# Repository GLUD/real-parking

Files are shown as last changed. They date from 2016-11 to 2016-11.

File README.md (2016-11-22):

# real-parking
Proyecto de Software y Hardware que pretente mejorar la movilidad de los parqueaderos a partir del análisis de datos.

Es un sistema escalable de parqueaderos. Busca ver toda la ciudad como un gran parqueadero y ayuda a gestionar de mejor manera el recurso espacial. Tiene un incentivo de gamificación con lo cuál se premia fidelidad a un parqueadero, entre otras cosas. Tiene un módulo de recomendaciones que dice cuál es el parqueadero mejor en relación precio/distancia del destino.

### INFORMACIÓN DE CONTACTO DESARROLLADORES ###

* Desarrollador: Jorge Ulises Useche Cuellar   
Ingeniero Electónico de la Udistrital FJC  
Movil: 3114813719  
Twitter: @juusechec   
LinkedIn: https://co.linkedin.com/in/juusechec  

* Desarrollador: Diego Javier Mena Amado  
Ingeniero Electrónico de la UDistrital FJC  
Movil: 3133067541  
Twitter: @DiegoJavierMena  
LinkedIn: https://www.linkedin.com/in/diego-javier-mena-amado-3357a873/en

* Desarrollador: Andrés Angarita  
Ingeniero de Sistemas de la UDistrital FJC  
Movil:   
Twitter: @   
LinkedIn:   

* Desarrollador: David Castelblanco  
Ingeniero de Sistemas de la UDistrital FJC  
Movil:   
Twitter: @   
LinkedIn:  

### Material de Presentación ###

https://www.youtube.com/watch?v=H8S8lVXx5Ek

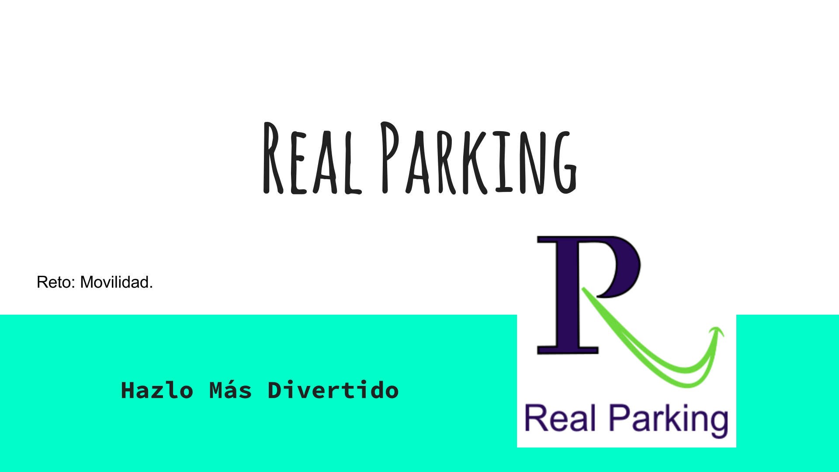
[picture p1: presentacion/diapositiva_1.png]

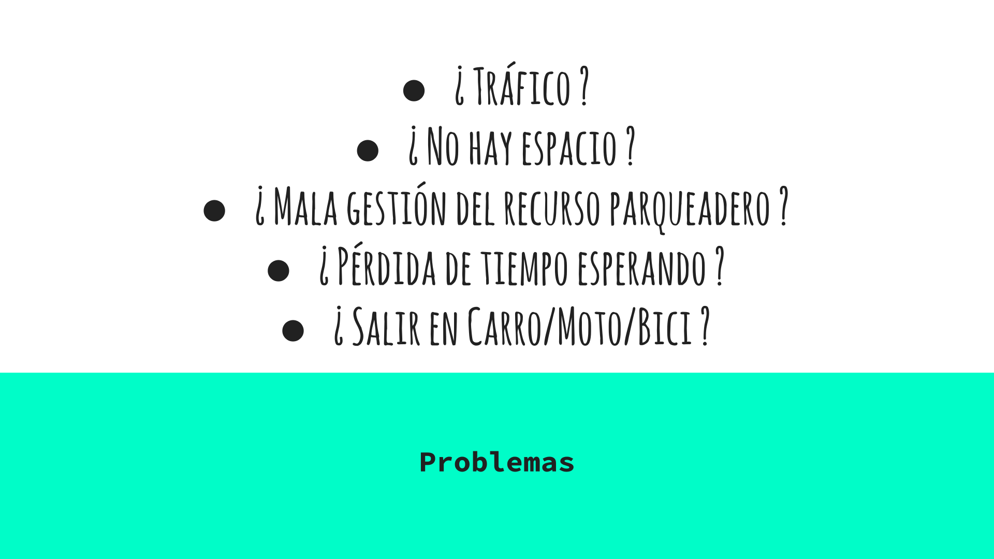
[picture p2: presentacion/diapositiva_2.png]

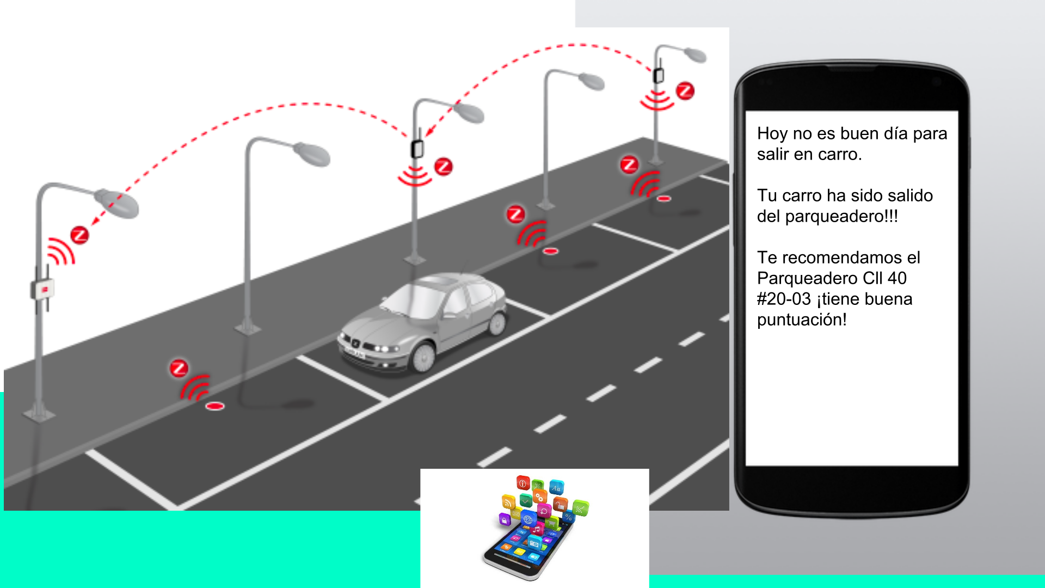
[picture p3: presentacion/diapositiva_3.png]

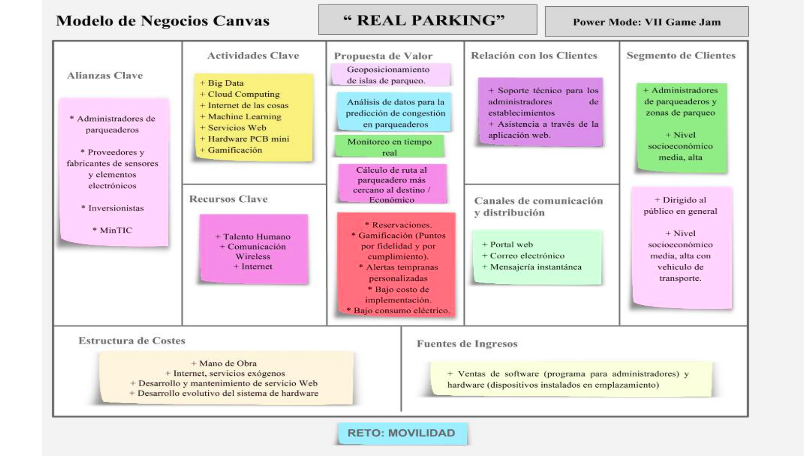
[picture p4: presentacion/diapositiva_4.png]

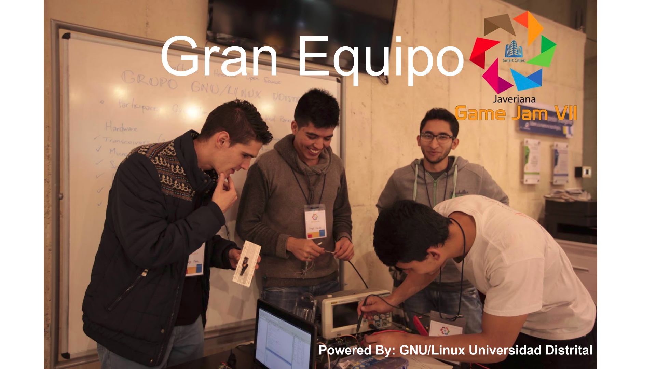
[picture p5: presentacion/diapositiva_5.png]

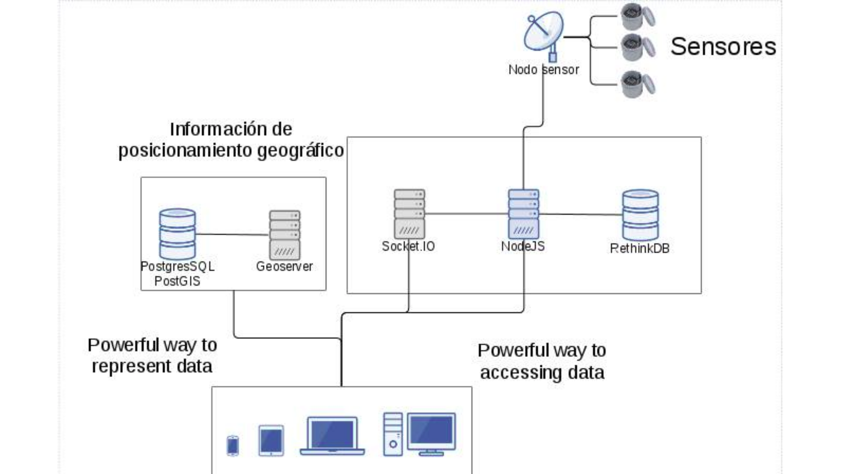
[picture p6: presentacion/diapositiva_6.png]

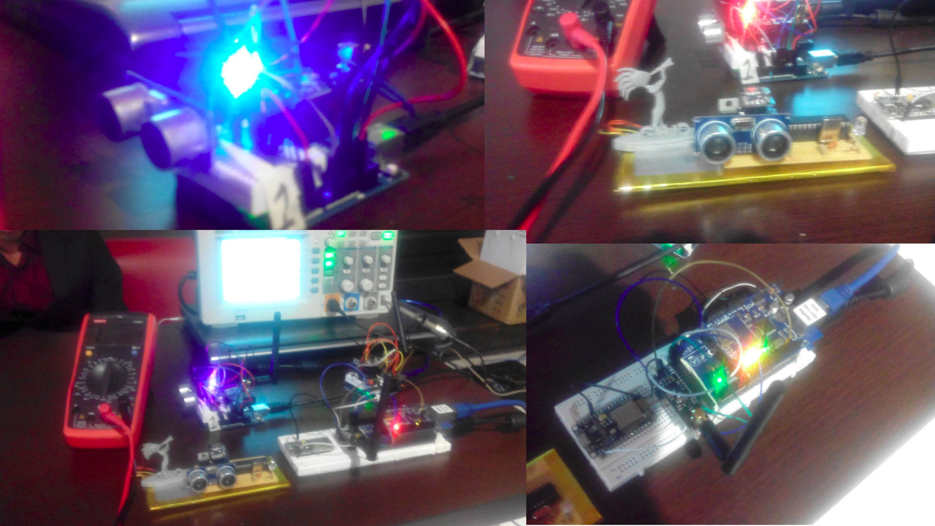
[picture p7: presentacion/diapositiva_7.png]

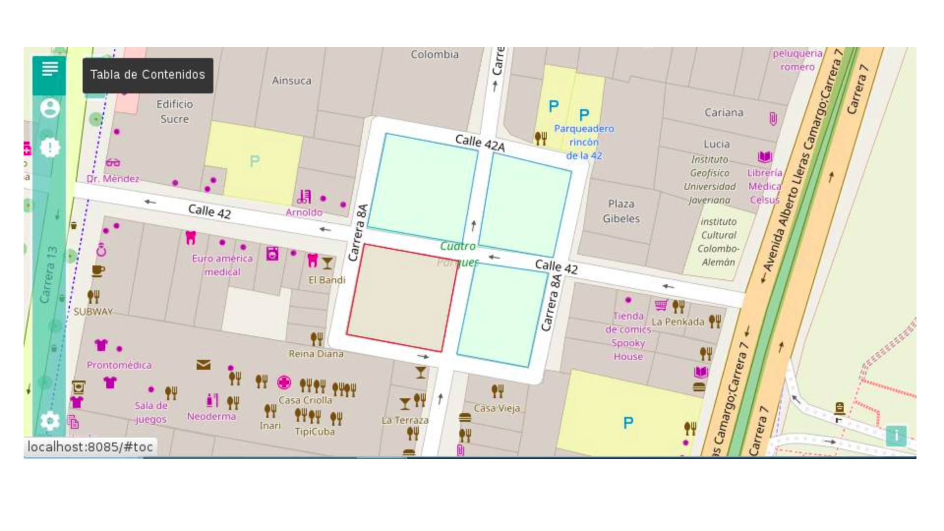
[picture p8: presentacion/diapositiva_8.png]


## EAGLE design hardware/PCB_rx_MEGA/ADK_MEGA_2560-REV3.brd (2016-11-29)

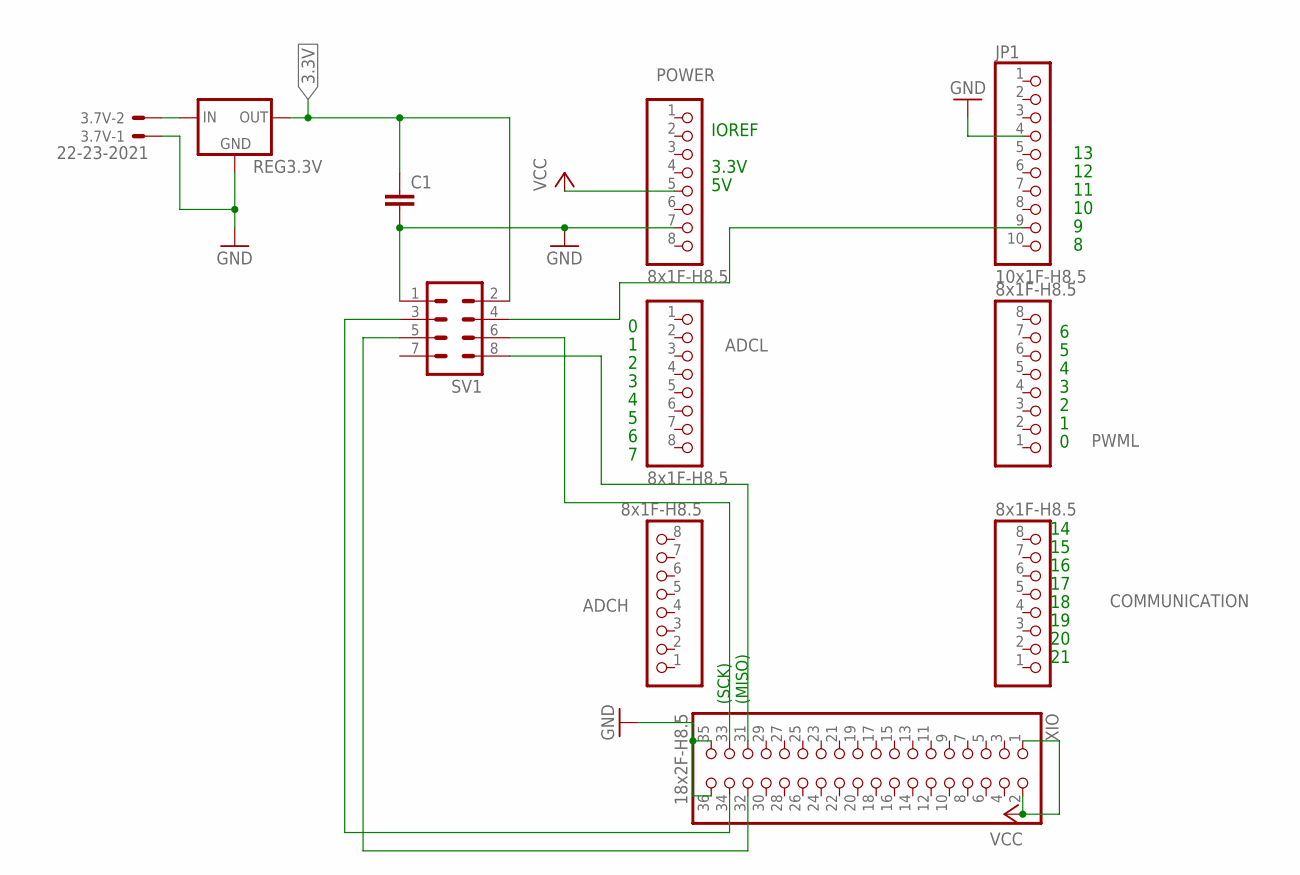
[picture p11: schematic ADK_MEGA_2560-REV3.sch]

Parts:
3.7V: 22-23-2021
ADCH: 8x1F-H8.5; 1X08
ADCL: 8x1F-H8.5; 1X08
C1: C-EU025-025X050; C025-025X050
COMMUNICATION: 8x1F-H8.5; 1X08
JP1: 10x1F-H8.5; 1X10
POWER: 8x1F-H8.5; 1X08
PWML: 8x1F-H8.5; 1X08
REG3.3V: 78XXL
SV1: MA04-2
XIO: 18x2F-H8.5; 2X18

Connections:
3.3V: C1.1, REG3.3V.OUT, SV1.2
GND: 3.7V.1, C1.2, JP1.4, POWER.7, REG3.3V.GND, SV1.1, XIO.35, XIO.36
unnamed: SV1.3, XIO.34
unnamed: SV1.5, XIO.32
unnamed: JP1.9, SV1.4
unnamed: SV1.6, XIO.33
unnamed: SV1.8, XIO.31
unnamed: 3.7V.2, REG3.3V.IN
VCC: POWER.5, XIO.1, XIO.2

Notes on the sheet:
(SCK)
(MISO)
IOREF
3.3V

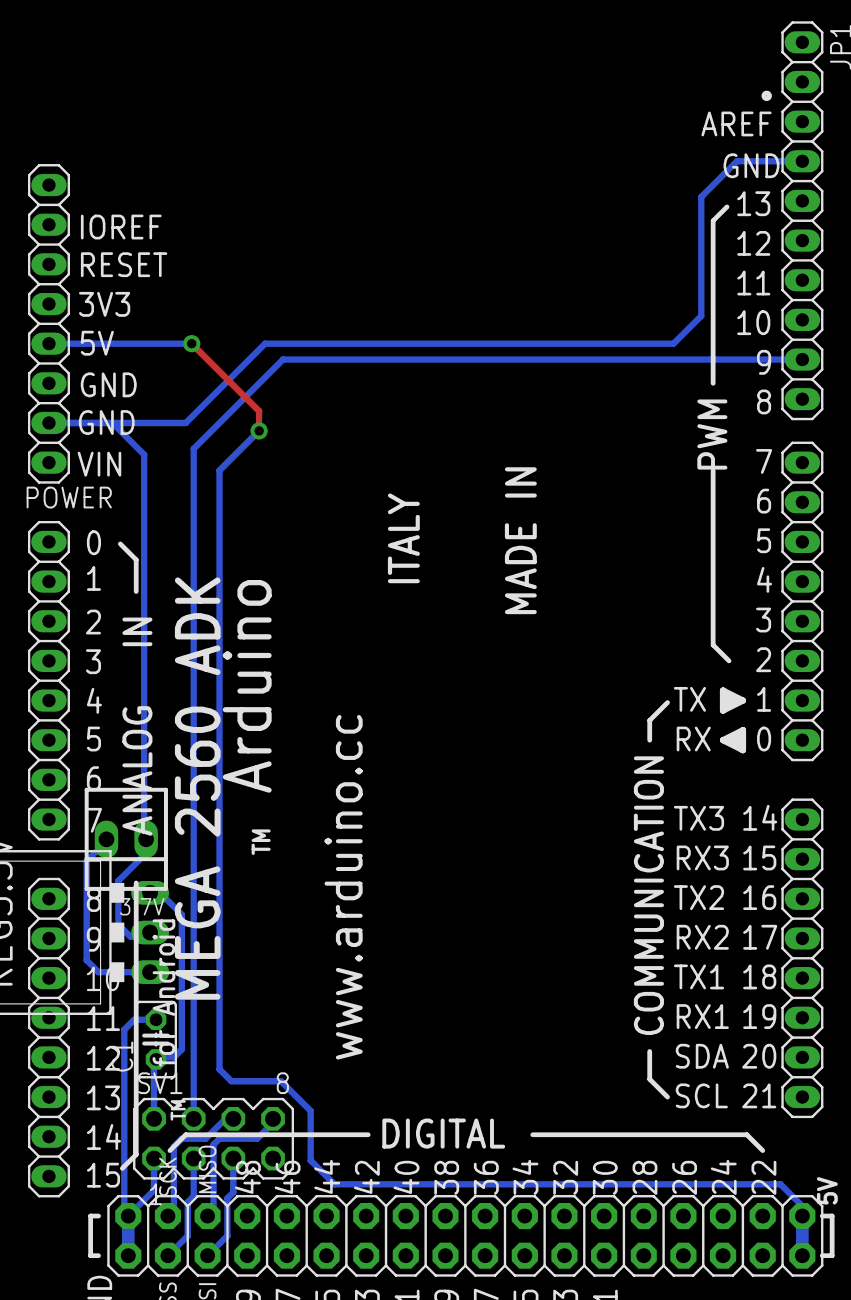
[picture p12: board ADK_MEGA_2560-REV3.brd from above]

Board: 2 copper layers, 11 parts (0 on the bottom side), 9 nets.

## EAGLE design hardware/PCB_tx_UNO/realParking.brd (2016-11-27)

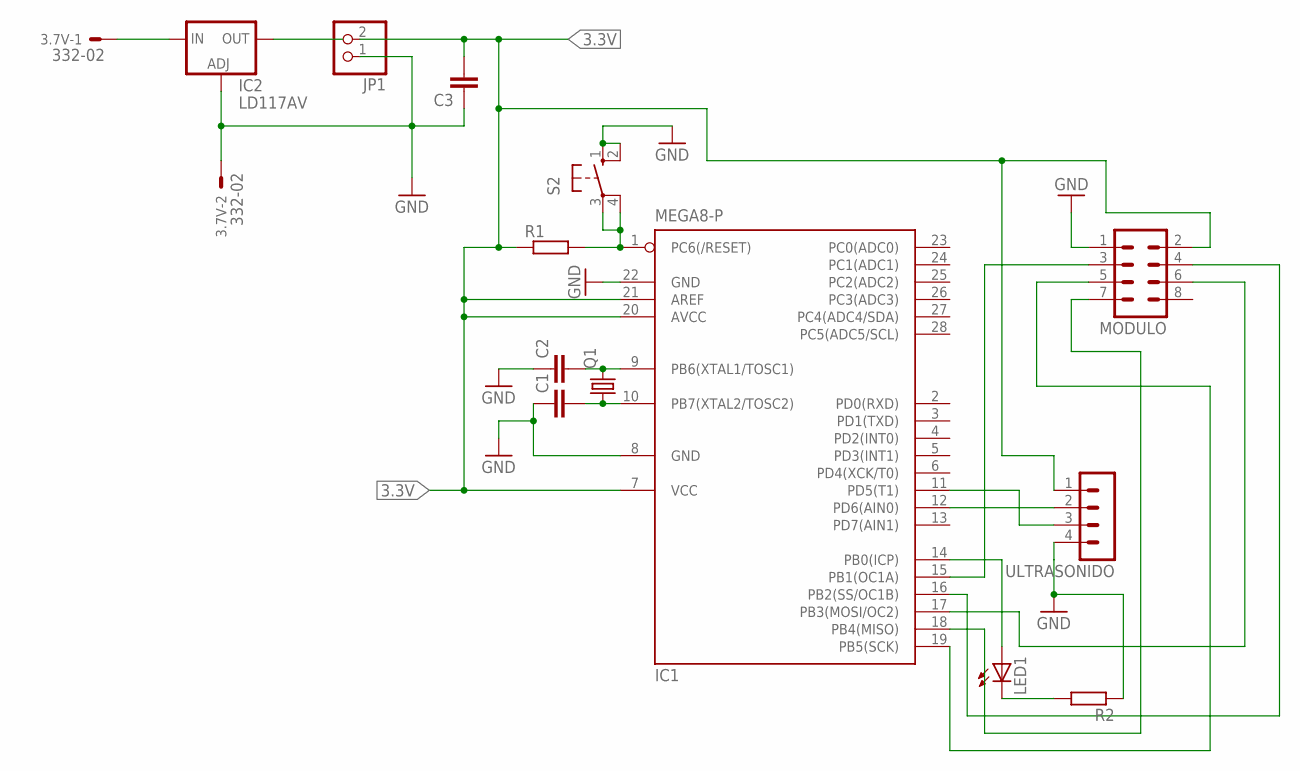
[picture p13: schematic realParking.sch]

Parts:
3.7V: 332-02
C1, C2, C3: C2,5-3; C2.5-3
IC1: MEGA8-P; DIL28-3
IC2: LD117AV; TO220L1
JP1: PINHD-1X2; 1X02
LED1: LED5MM
MODULO: MA04-2
Q1: CRYSTALTC26V; TC26V
R1, R2: R-EU_0204/5; 0204/5
S2: 10-XX; B3F-10XX
ULTRASONIDO: MA04-1

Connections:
3.3V: C3.2, IC1.7 (VCC), IC1.20 (AVCC), IC1.21 (AREF), JP1.2, MODULO.2, R1.1, ULTRASONIDO.1
GND: 3.7V.2, C1.1, C2.1, C3.1, IC1.8 (GND), IC1.22 (GND), IC2.1 (ADJ), JP1.1, MODULO.1, R2.1, S2.1 (S), S2.2 (S1), ULTRASONIDO.4
unnamed: 3.7V.1, IC2.3 (IN)
unnamed: IC1.12 (PD6(AIN0)), ULTRASONIDO.2
unnamed: IC1.11 (PD5(T1)), ULTRASONIDO.3
unnamed: LED1.K (C), R2.2
unnamed: IC1.14 (PB0(ICP)), LED1.A
unnamed: IC1.15 (PB1(OC1A)), MODULO.3
unnamed: IC1.16 (PB2(SS/OC1B)), MODULO.4
unnamed: IC1.17 (PB3(MOSI/OC2)), MODULO.6
unnamed: IC1.18 (PB4(MISO)), MODULO.7
unnamed: IC1.19 (PB5(SCK)), MODULO.5
unnamed: C2.2, IC1.9 (PB6(XTAL1/TOSC1)), Q1.2
unnamed: C1.2, IC1.10 (PB7(XTAL2/TOSC2)), Q1.1
unnamed: IC1.1 (PC6(/RESET)), R1.2, S2.3, S2.4 (P1)

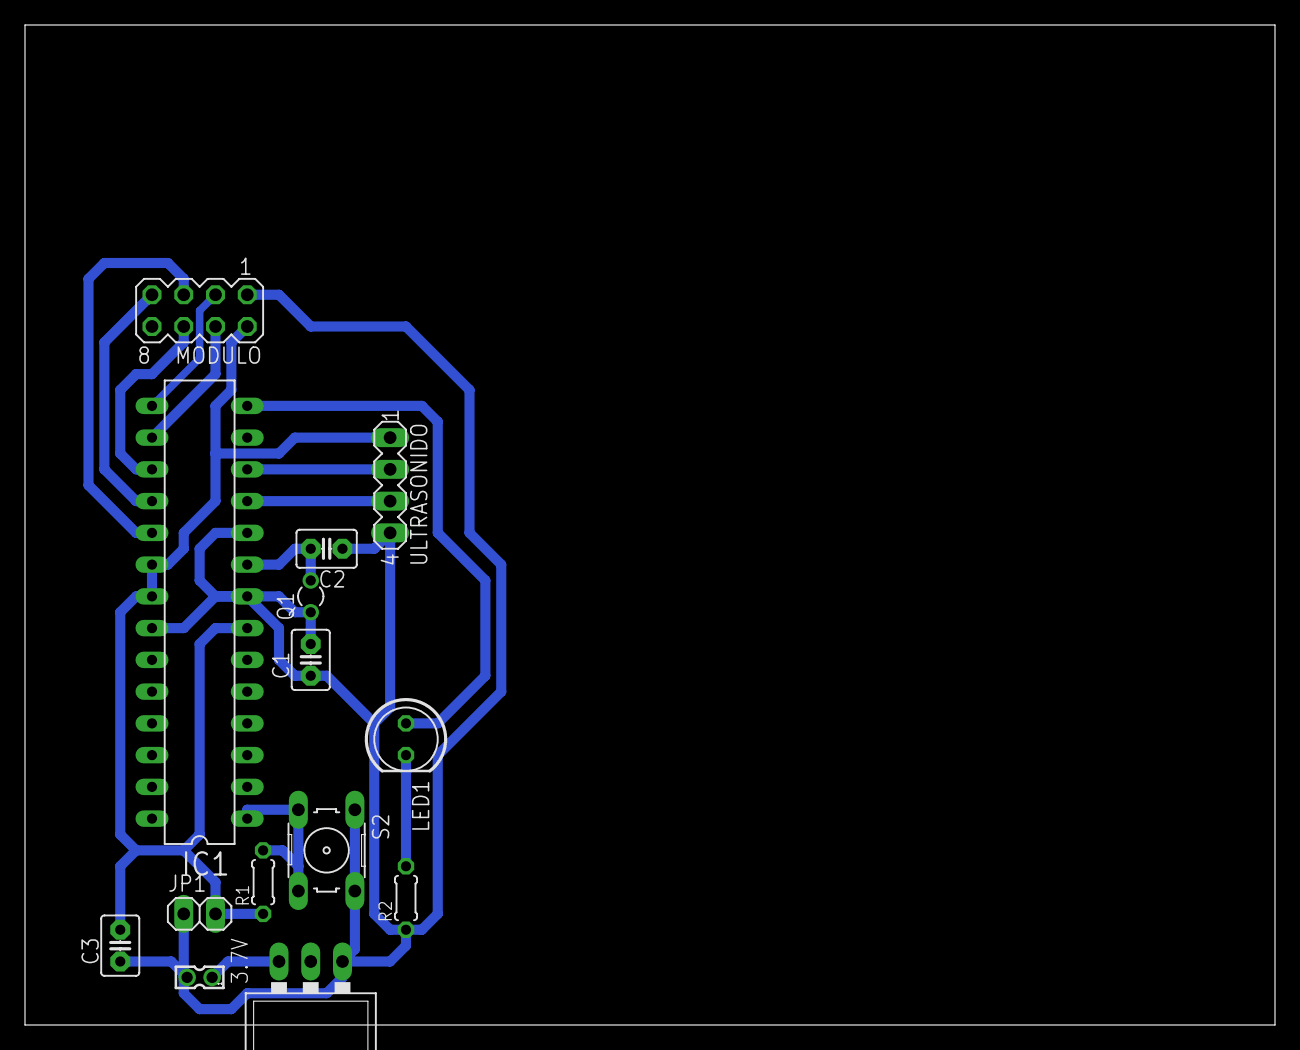
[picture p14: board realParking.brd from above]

Board: 2 copper layers, 100.0 x 80.0 mm, 14 parts (0 on the bottom side), 15 nets.

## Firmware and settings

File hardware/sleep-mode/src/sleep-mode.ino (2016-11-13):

// http://www.prometec.net/el-modo-sleep-en-arduino/
// https://github.com/rocketscream/Low-Power
#include "LowPower.h"
int LED = 13;

void setup() { pinMode(13, OUTPUT); }
void loop() {
  // SLEEP_15MS
  // SLEEP_30MS
  // SLEEP_60MS
  // SLEEP_120MS
  // SLEEP_250MS
  // SLEEP_500MS
  // SLEEP_1S
  // SLEEP_2S
  // SLEEP_4S
  // SLEEP_8S
  // SLEEP_FOREVER

  LowPower.powerDown(SLEEP_8S, ADC_OFF, BOD_OFF);
  // for(int i = 0 ;  i  <  16 ; i++){
  //   //de 4 x 15 segundos = 60
  //   LowPower.powerDown(SLEEP_4S, ADC_OFF, BOD_OFF);
  // }
  digitalWrite(LED, HIGH);
  delay(5000);
  digitalWrite(LED, LOW);
  delay(5000);
  digitalWrite(LED, HIGH);
}

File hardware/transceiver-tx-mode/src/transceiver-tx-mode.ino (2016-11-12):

/*  ----------------------------------------------------------------
    http://www.prometec.net/duplex-nrf2401
    Prog_79B_Emisor

    Usando un NRF2401 para comunicar dos Arduinos en modo Duplex
    Programa Emisor:
   --------------------------------------------------------------------
 */
#include <SPI.h>
#include "nRF24L01.h"
#include "RF24.h"

RF24 radio(9,10);

const uint64_t pipes[2] = { 0xF0F0F0F0E1LL, 0xF0F0F0F0D2LL }; //LongLong = 64 bits.

void setup(void)
{
  pinMode(10, OUTPUT);
  Serial.begin(9600);
  radio.begin();

  radio.setRetries(15,15); // Maximos reintentos
  //radio.setPayloadSize(8);   // Reduce el payload de 32 si tienes problemas

  // Open pipes to other nodes for communication
  radio.openWritingPipe(pipes[0]);
  radio.openReadingPipe(1,pipes[1]);
}

void loop(void)
{
  radio.stopListening(); // Paramos la escucha para poder hablar
  unsigned long time = millis();
  Serial.print("Enviando  ");
  Serial.println(time);
  bool ok = radio.write( &time, sizeof(unsigned long) );

  if (ok)
    Serial.println("ok...");
  else
    Serial.println("failed");

  radio.startListening(); //Volvemos a la escucha

  unsigned long started_waiting_at = millis();
  bool timeout = false;
  while ( !radio.available() && !timeout ) // Esperasmos repsuesta hasta 200ms
    if (millis() - started_waiting_at > 200 ) timeout = true;

  if ( timeout )
    Serial.println("Failed, response timed out");
  else
  { // Leemos el mensaje recibido
    unsigned long got_time;
    radio.read( &got_time, sizeof(unsigned long) );

    Serial.print("Respuesta = ");
    Serial.println(got_time);
  }
  delay(500);
}

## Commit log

2016-11-12 Se crea el archivo package.json, y se instalan algunas dependencias
2016-11-12 Se crea emisor de eventos básico
2016-11-12 Se empieza la implementación del index del proyecto, y el servidor de los sockets
2016-11-12 Se empezo a implementar el modulo que se comunica con el nodo central del parqueadero
2016-11-12 Se añade algoritmo para la recepcion de tiempo generado por el transmisor
2016-11-12 Se añade algoritmo para la detección de vehiculos con ultrasonido
2016-11-12 Se implementa un proxy inverso para resolver problemas de cors con el geoServer
2016-11-12 Se crea evento para seleccionar una isla, y cambiar su estado
2016-11-12 Se implemento la funcionalidad de tiempo real, para notificar al cliente cuando un vehiculo ingresa a una isla, o la abandona
2016-11-12 Se organizan las dependencias del package.json, y se crea un script de construcción
2016-11-12 Se crea el componente visual, que se encarga de gestionar los cobros
2016-11-12 Se suben los cambios de archivos miscelaneos
2016-11-13 Se agrega código de sleep ArduinoMega, 20mA de Ahorro
2016-11-13 Se implementan end points del API para actualizar, y consultar registros
2016-11-13 Parte del API relacionada con consultas, y su respectiva comunicación desde el cliente
2016-11-13 Se implementa la funcionalidad del modelo en la vista de cobro, se utiliza una libreria para emitir eventos
2016-11-13 Se instala, y se integra el middleware body-parser
2016-11-13 Se implementa el modulo de la base de datos
2016-11-13 Se implementa un metodo para buscar registros por id, y se crea una interfaz, que controla el número de instancias de la base de datos
2016-11-13 Se usa la implementación de la base de datos para almacenar y actualizar información
2016-11-13 Se corrigen algunos errores en el cliente
2016-11-13 Se envían datos de Ejemplo de Id Isla y Estado Isla (ocupado, vacio, baja bateria)
2016-11-13 Nodo centrar recibe 2 bytes de información sobre estado e isla
2016-11-13 Se hacen algunos ajustes en el código
2016-11-13 se añade esquematico en fritzing para ilsa-emisor
    [realParking.fzz]
2016-11-13 Código del sensor de isla 2 con interruptor como cambio de estado
2016-11-14 Se agrega imagenes de diapositivas
2016-11-22 Se añade diseño PCB en Eagle del prototipo-receptor
    [realParking.brd, realParking.sch]
2016-11-27 Se arregla diseño PCB del modulo transmisor
    [realParking.brd, realParking.sch]
2016-11-29 Se añade PCB_rx_MEGA
    [ADK_MEGA_2560-REV3.brd, ADK_MEGA_2560-REV3.sch, realParking.brd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]
2016-11-29 Se añade modulo de comunicaciones junto con regulador al diseño de la shield para el nodo central
    [ADK_MEGA_2560-REV3.brd, ADK_MEGA_2560-REV3.sch]
